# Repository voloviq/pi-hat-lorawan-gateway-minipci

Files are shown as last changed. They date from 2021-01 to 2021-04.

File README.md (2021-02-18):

# pi-hat-lorawan-gateway-minipci
Pi Hat with mini pci express connector for lorawan gateway rk833

PCB View

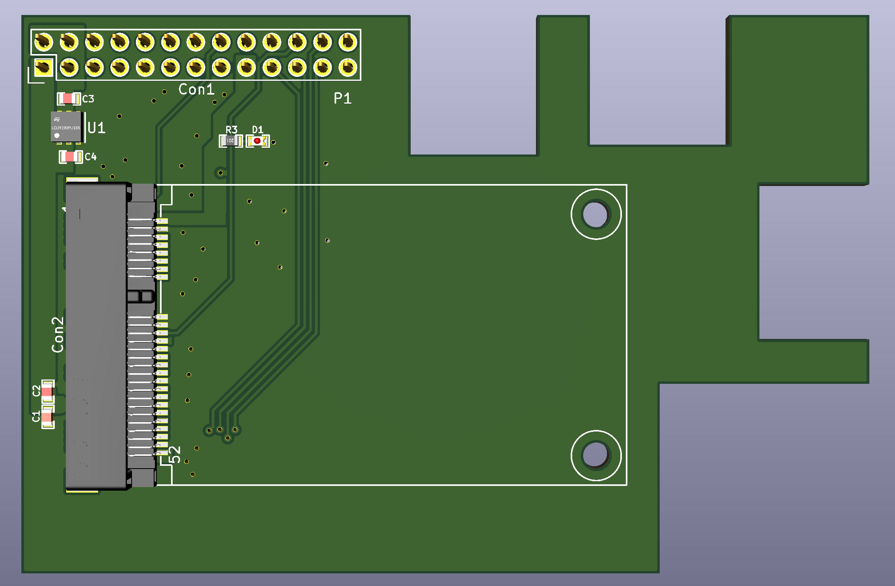
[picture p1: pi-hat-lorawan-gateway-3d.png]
PCB_3D


This is first prototype version and can have some connection mistakes. Please check it before use!.

This update was made in lates KiCad version 5.99.

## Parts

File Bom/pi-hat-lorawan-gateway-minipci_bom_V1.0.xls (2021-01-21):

Component | Description | References | Value | Footprint | Notice | Quantity Per PCB | Supplier | Supplier Part Number | Manufacturer | Manufacturer Part Number | URL | LCSC Part #(optional)
1 | 100nF, 50V, X7R, 5%, -55°C to +125°C | C1 | 100n | 0603 |  | 1 | TME | CL10B104JB8NNNC | SAMSUNG | CL10B104JB8NNNC | https://www.tme.eu/pl/details/cl10b104jb8nnnc/kondensatory-mlcc-smd-0603/samsung/ | C14663
2 | 10uF, 6.3V, X5R, 10%, -55°C to +85°C | C2 C3 C4 | 10uF | 0603 |  | 3 | TME | C0603C106M9PAC | KEMET | C0603C106M9PACTU | https://www.tme.eu/pl/details/c0603c106m9pac/kondensatory-mlcc-smd-0603/kemet/c0603c106m9pactu/ | C162265
3 | TE Connectivity SMD Gold Flash Mini PCI-Express Connector | Con2 | 2041119-1 | 2041119-1 |  | 1 | Mouser | 571-2041119-1 | TE Connectivity | 2041119-1 | https://pl.mouser.com/ProductDetail/TE-Connectivity/2041119-1?qs=%252BD5sUuPmlApmv1YR%252BaSc%252Bw%3D%3D
4 | Socket, pin strips, female, PIN, 26, straight, 2.54mm, THT, 2x13 | Con1 | RPi-Header-2x13 | Header_Socket_2x13x2_54mm |  | 1 | TME | ZL262-26DG | CONNFLY | DS1023-2*13S21 | https://www.tme.eu/pl/en/details/zl262-26dg/pin-headers/connfly/ds1023-2-13s21/
5 | Red LED 0603 630nm 20mA 200...350mcd 120° -40°C to +85°C | D1 | KPG-1608SURKC-T | 0603 |  | 1 | TME | KPG-1608SURKC-T | KINGBRIGHT ELECTRONIC | KPG-1608SURKC-T | https://www.tme.eu/pl/details/kpg-1608surkc-t/diody-led-smd-kolorowe/kingbright-electronic/ | C192315
6 | 200Ω 0,1W ±5% -55...155°C | R3 | 200R | 0603 |  | 1 | TME | SMD0603-200R | ROYAL OHM | 0603SAJ0201T5E | https://www.tme.eu/pl/details/smd0603-200r/rezystory-smd-0603/royal-ohm/0603saj0201t5e/ | C8218
7 | 4.7kΩ 0,1W ±5% -55...155°C | R1 R2 | 4k7 | 0603 |  | 2 | TME | SMD0603-4K7-1% | ROYAL OHM | 0603SAF4701T5E | https://www.tme.eu/pl/details/smd0603-4k7-1%2525/rezystory-smd-0603/royal-ohm/0603saf4701t5e/
8 | Single 3.3V 2A Ultra LDO with enable signal | U1 | LD39200 | DFN-6 |  | 1 | Mouser | 511-LD39200PU33R | TOSHIBA | LD39200PU33R | https://pl.mouser.com/ProductDetail/STMicroelectronics/LD39200PU33R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 | C222192

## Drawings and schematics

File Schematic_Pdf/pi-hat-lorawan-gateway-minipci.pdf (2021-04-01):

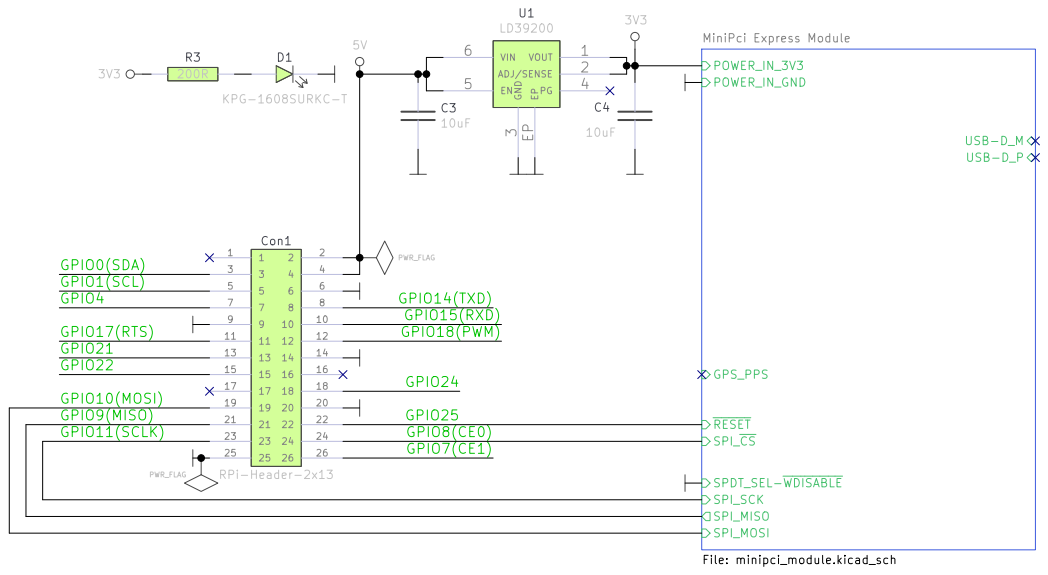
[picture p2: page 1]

GPIO9(MISO)
GPIO11(SCLK) | GPIO8(CE0)

GPIO7(CE1)

File: pi-hat-lorawan-gateway-minipci.kicad_sch Sheet: / Embedded System Labs

Id: 1/2 Title: Pi Hat with mini pci express connector for lorawan gateway rk833

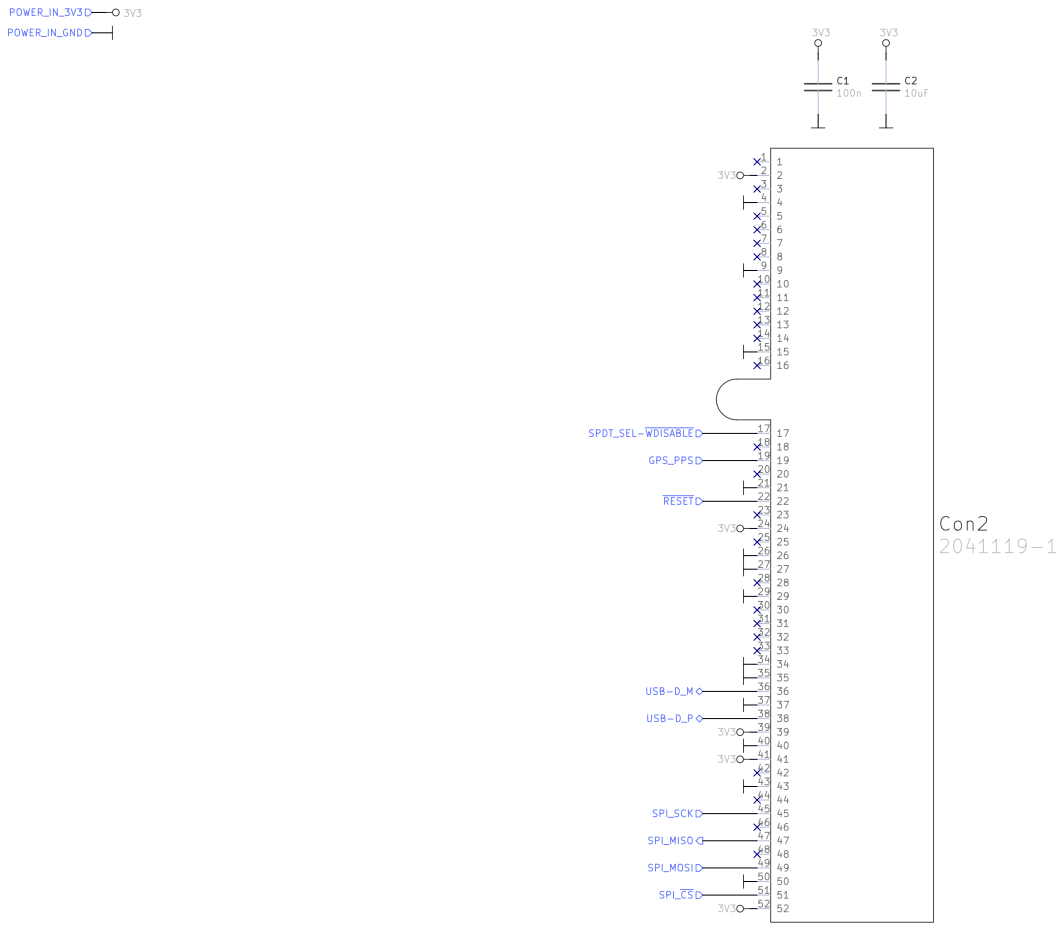
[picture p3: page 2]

Sheet: /MiniPci Express Module/
File: minipci_module.kicad_sch
Id: 2/2 Title: Minipci Module

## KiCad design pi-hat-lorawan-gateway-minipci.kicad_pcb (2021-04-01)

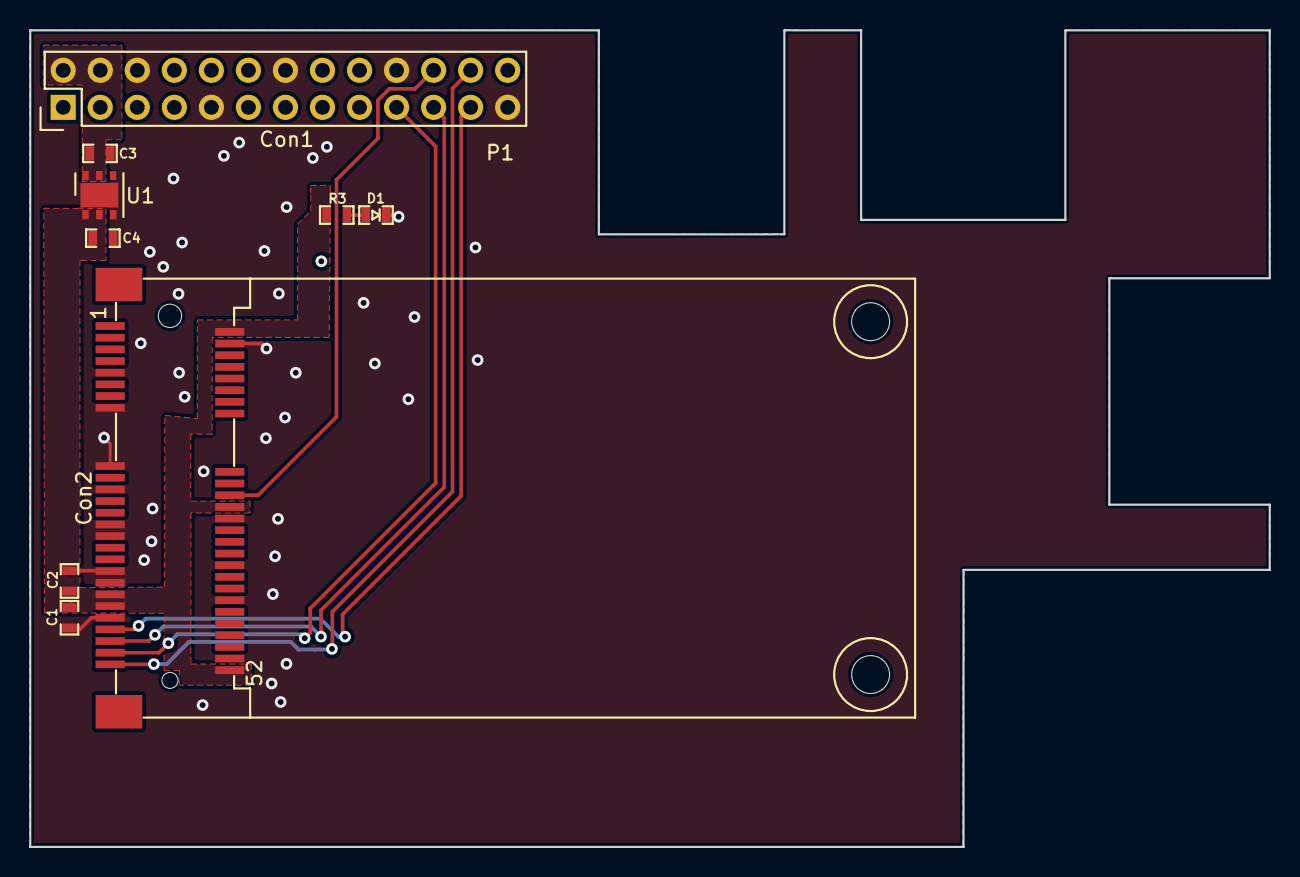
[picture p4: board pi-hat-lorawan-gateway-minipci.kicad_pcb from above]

Board: 2 copper layers, 85.0 x 56.0 mm, 9 parts (0 on the bottom side), 9 nets.

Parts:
C1: 100n; 100nF_0603
C2, C3, C4: 10uF; 10uF_10V_0603
Con1: RPi-Header-2x13; Header_Socket_2x13x2_54mm
Con2: 2041119-1
D1: KPG-1608SURKC-T; LED_KPG-1608SURKC-T
R3: 200R; 200R_0603
U1: LD39200; LD39200PU33R

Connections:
3V3: C1.1, C2.1, C4.1, Con2.2, Con2.24, Con2.39, Con2.41, Con2.52, R3.2, U1.1 (VOUT), U1.2 (ADJ/SENSE)
5V: C3.1, Con1.2, Con1.4, U1.5 (EN), U1.6 (VIN)
/GPIO8(CE0): Con1.24, Con2.51
/GPIO9(MISO): Con1.21, Con2.47
/GPIO10(MOSI): Con1.19, Con2.49
/GPIO11(SCLK): Con1.23, Con2.45
/GPIO25: Con1.22, Con2.22
GND: C1.2, C2.2, C3.2, C4.2, Con1.6, Con1.9, Con1.14, Con1.20, Con1.25, Con2.4, Con2.9, Con2.15, Con2.17, Con2.21, Con2.26, Con2.27, Con2.29, Con2.34, Con2.35, Con2.37, Con2.40, Con2.43, Con2.50, D1.2 (K), U1.3 (GND), U1.EP
unnamed: D1.1 (A), R3.1

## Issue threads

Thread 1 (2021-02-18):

Wrong pins connected to board

voloviq, 2021-02-18:
Probably wrong pin connected to pci express connector. Misunderstand supplier picture with pin description.

voloviq, 2021-02-18:
Captured picture from supplier

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

After take a look at pcb board there is no track to pads related with spi.

After investigation discover following pinout

pin51 - CS (should be connected to RPI pin24)
pin49 - MOSI (should be connected to RPI pin19)
pin47 - MISO (should be connected to RPI pin21)
pin45 - SCK (should be connected to RPI pin23)
pin22 - RESET (should be connected to RPI  pin22)
pin17 - SPDT_SEL (for SPI version connected to GND)
pin19 - GPS_PPS (connected to free RPI GPIO)

voloviq, 2021-02-18:
Applied, mentioned connection. Regenerated gerbers and all production files.

Closed 2021-02-18.

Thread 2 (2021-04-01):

Pin SPDT_SEL-WDISABLE wrong assigned

voloviq, 2021-04-01:
During bring up discover that SPDT_SEL_WDISABLE pin is wrong assigned to pin 20 but should be to 17.

Closed 2025-02-03.

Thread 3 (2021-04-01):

Power rail 3.3V wrong connected to LDO

voloviq, 2021-04-01:
Discover that LDO 3.3 connected to 3.3V rais cause RPI4 not starts. Remove 3.3V rail from LDO. Affected to all branches.

Closed 2025-02-03.

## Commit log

2021-01-21 Finalized project and generated all production files
    [minipci_module.sch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]
2021-02-18 Applied Issue 1, performed valid SPI connection to RPi
    [minipci_module.kicad_sch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]
2021-04-01 Applied issue, regenerated gerbers
    [minipci_module.kicad_sch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]
